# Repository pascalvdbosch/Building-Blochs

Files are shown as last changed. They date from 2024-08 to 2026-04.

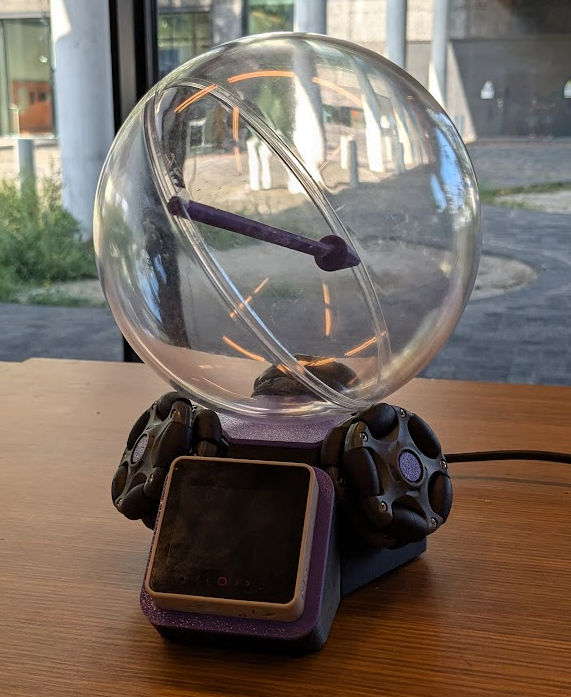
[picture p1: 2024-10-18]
Doc/Building-Bloch.PNG

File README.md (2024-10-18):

# Building Blochs
This Physical representation of a [bloch sphere](https://en.wikipedia.org/wiki/Bloch_sphere) was developed by Quantum Delta NL and The Technology Center at the University of Amsterdam for various outreach and educational purposes. The files and documentation on this repository should be sufficient for anyone to build this model and get it running.

Finished Building Bloch

## Bill of Materials
| Item | Quantity |  ~Price(€) | Source | Remarks|
|--|--|--|--|--|
| Base | 1 | 1.00 | 3D print | print upside down |
| M5 housing| 1 | 0.60 | 3D print |  |
| Lid - blank| 1 | 0.20 | 3D print |  |
|  M5 frame | 1 | 0.20 | 3D print |  |
| Axle adapter| 3 | 0.15 | 3D print |  |
| Arrow| 1 | 0.10 | 3D print | print slow with brim for stability  |
| M5Stack CoreS3 SE |1|35.00 |[M5stack](https://shop.m5stack.com/products/m5stack-cores3-se-iot-controller-w-o-battery-bottom) | |
| Stepmotor Driver Module v1.1 |1 |20.00 | [M5stack](https://shop.m5stack.com/products/stepmotor-driver-module-v1-1-hr8825)|some connector modifications required |
|58mm Plastic Omni Wheel | 3|26.55 |[Robotshop](https://eu.robotshop.com/products/58mm-plastic-omni-wheel-compatible-servos-lego-mindstorms-nxt) | |
| Plastic Sphere|1 | | | |
|Adafruit USB PD Breakout |1 |5.50 |[Adafruit](https://www.adafruit.com/product/5807) | |
|USB PD power supply |1 | | |Any that can supply 9V should work |
|rubber feet | | | | |
|bolts |4 | | | |
|nuts |4 | | | |
|ty-rap | | | | |
| connectors 4 pin male| 3| | | |
| connectors 3 pin male|1 | | | |
| connectors 4 pin female|3 | | | |
| connectors 3 pin female|1 | | | |
| connectors spring contacts|14 | | | get some spare extras|

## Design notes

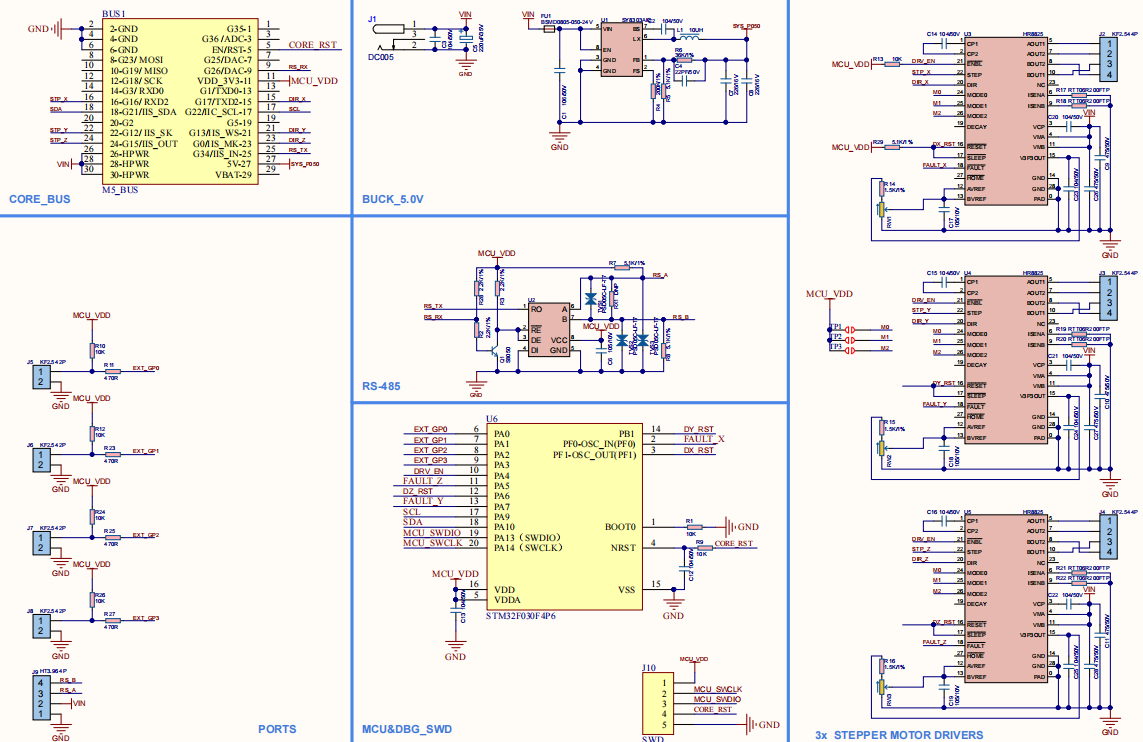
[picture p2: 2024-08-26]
Doc/m5stack-stepmotordriver-v11.png

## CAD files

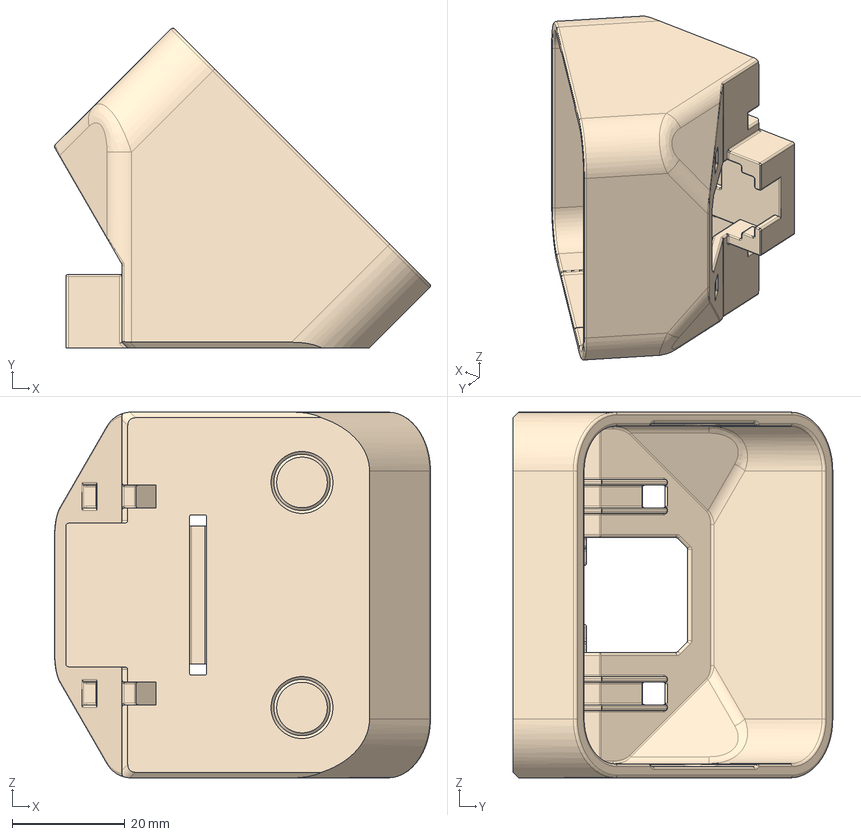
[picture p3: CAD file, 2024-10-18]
Building-Blochs-3Dmodels/23-0093 M5 housing 01-10-2024.stp
66.8 x 56.8 x 65.0 mm

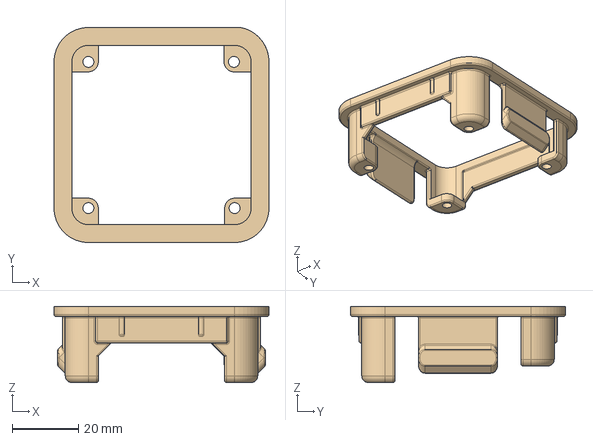
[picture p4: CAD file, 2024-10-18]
Building-Blochs-3Dmodels/23-0093 M5 frame 01-10-2024.stp
65.0 x 65.0 x 23.0 mm

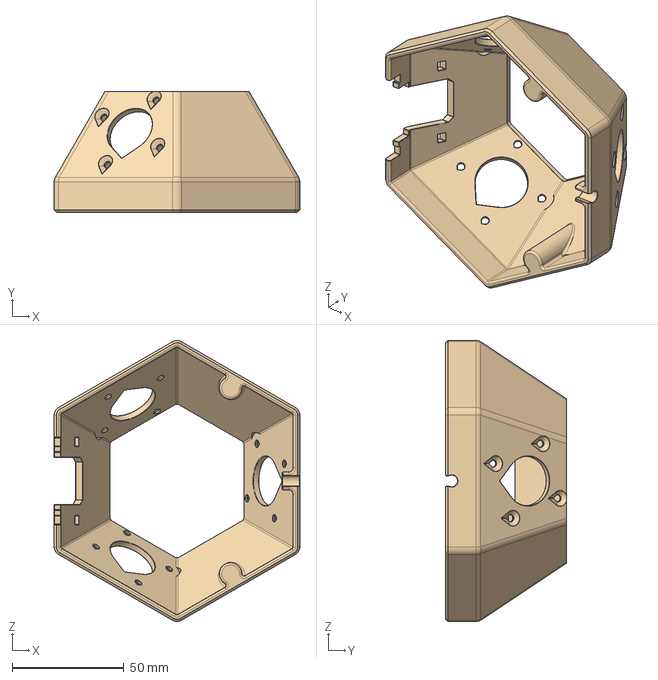
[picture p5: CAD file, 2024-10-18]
Building-Blochs-3Dmodels/23-0093 Base 01-10-2024.stp
110.0 x 54.0 x 125.8 mm

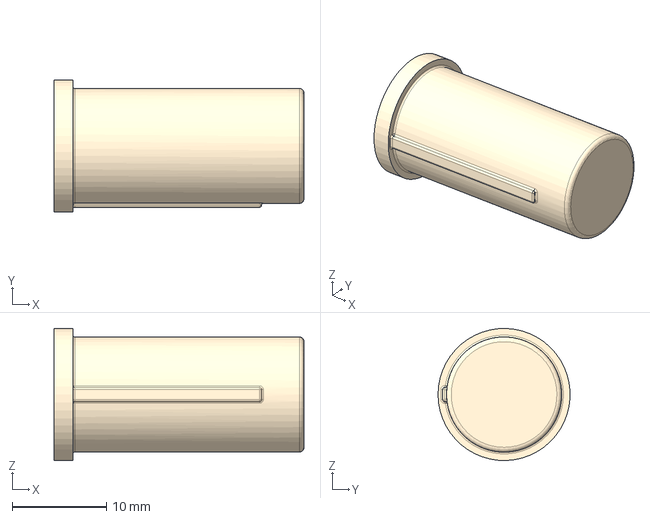
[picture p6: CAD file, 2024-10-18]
Building-Blochs-3Dmodels/23-0093 Axle adapter 01-10-2024.stp
26.5 x 14.0 x 14.0 mm

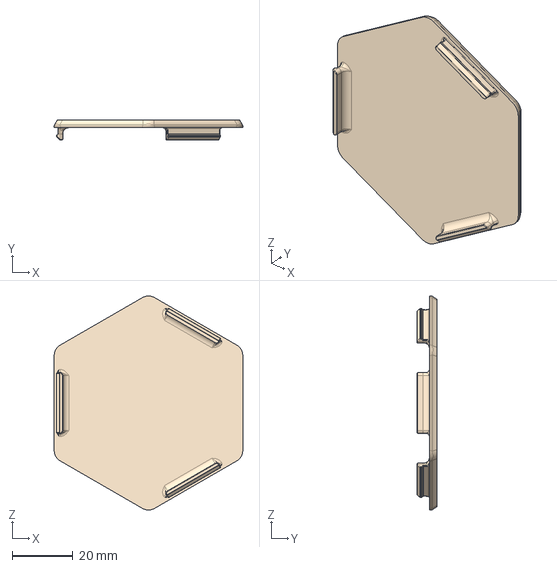
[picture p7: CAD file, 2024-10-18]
Building-Blochs-3Dmodels/23-0093 Lid - blank 01-10-2024.stp
62.0 x 6.50 x 70.3 mm

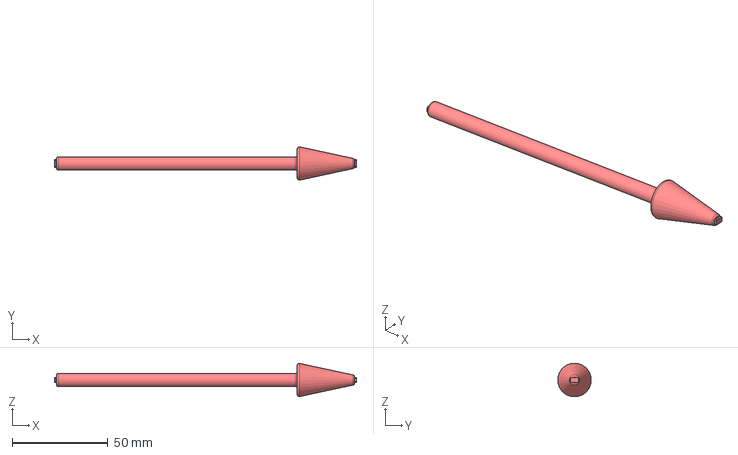
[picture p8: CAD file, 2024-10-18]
Building-Blochs-3Dmodels/23-0093 Arrow 01-10-2024.stp
158.0 x 17.5 x 17.5 mm

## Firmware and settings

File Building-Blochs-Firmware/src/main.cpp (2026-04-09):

#include <Arduino.h>
#include <AccelStepper.h>
#include "config.h"
#include <ArduinoEigenDense.h>

#include "log.h"
#include "bloch.h"
#include "gui.h"
#include "receiver.h"

#include "m5stack-data.h"

BlochSphere bloch;

using namespace Eigen;

void setup()
{
    Serial.begin(115200);
    // Wait until serial is enumerated
    Serial.printf("Serial\n");
    // USBSerial.printf("USBSerial");

    Serial.printf("receiver_setup\n");

    receiver_setup();

    Serial.printf("gui_begin\n");

    gui_begin();

    Serial.printf("bloch.begin\n");

    bloch.begin();

    Serial.printf("initial rotate\n");

    bloch.rotate(Vector3d(0, 0, 1), STEPS_PER_ROTATION);

    DBG("Setup done.");
};

void loop()
{
    gui_loop();
    receiver_loop();

    bloch.loop();
};

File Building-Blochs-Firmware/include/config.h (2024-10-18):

#ifndef __CONFIG_H
#define __CONFIG_H

#define VERSIONSTR "20241018"

#define MOTOR_ANGLE_DEG         30
#define BASE_Z_ROTATION_DEG     30

// Globe Diam : 160mm
// Wheel Diam : 58mm
// Motor steps: 200 * microstepping = 200*16 = 3200
// Steps per revolution: 3200 steps / 58mm * 160mm = 8827
#define STEPS_PER_ROTATION         		(3200*160/58)

// #define MOTORS_MAX_SPEED        20000
// #define MOTORS_MAX_ACCEL		5000
#define MOTORS_MAX_SPEED        15000
#define MOTORS_MAX_ACCEL		4000

#define DISPLAY_MAXFPS			30					// LVGL Update rate (timer_event)
#define DISPLAY_WIDTH			320
#define DISPLAY_HEIGHT			240

// PINS

#endif // __CONFIG_H

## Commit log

2023-04-04 hardware test new led ring
2023-04-04 added buttons and some led effects
2023-04-04 further button code and ball control
2023-04-04 further button code and ball control #2
2023-04-07 Converted double calcs to Matrix/Vector calculations with libeigen, added block calc(not working), bloch_calc.html (working)
    [bloch.cpp, main.cpp]
2023-04-12 vector[3] to matrix, fixed calc index error, printMatrix
    [bloch.cpp]
2024-08-26 made it run by resetting motors
    [bloch.cpp, main.cpp]
2024-10-01 added 3d models
    [23-0093 Arrow 01-10-2024.stp, 23-0093 Axle adapter 01-10-2024.stp, 23-0093 Base 01-10-2024.stp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]
2024-10-15 Fix pin screw-up
2024-10-15 Add 4 button gui
2024-10-15 Add state _NONE so we print the first transition as well
2024-10-18 only one imu in cores3
2026-04-09 extra gates and reset
    [bloch.cpp]
